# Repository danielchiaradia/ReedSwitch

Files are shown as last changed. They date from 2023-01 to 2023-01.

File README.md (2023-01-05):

# ReedSwitch
Simple Door/Window contact with low quiescence current of around 5µA (according to my cheap multimeter ...). There is quite some power loss on the ESP development board caused by the regulator, serial converter and other components. However, it will only be powered for a short amount time, so it's not worth going the hard naked ESP way here.

# BOM
- ESP01
- Attiny85
- LiFePO4 Battery
- 2 x 3K3 Ohm resistor
- 410 µF capacitor
- Reed Switch with two terminals or alternatively a normally closed reed switch.
- 1xP-Channel MOSFET (e.g.NDP6020P)

# How it works
The attiny will be turned on by the reed switch and then turns the ESP via the MOSFET on. The ESP sends the current state of the reed switch to a REST service. After sending the data, the ESP signals to the attiny to turn of the power.

# Quiescence current
Around 5-10 µA with closed reed switch. Open switch will cause around 20-30 µA current (probably the closed terminal draws some current)

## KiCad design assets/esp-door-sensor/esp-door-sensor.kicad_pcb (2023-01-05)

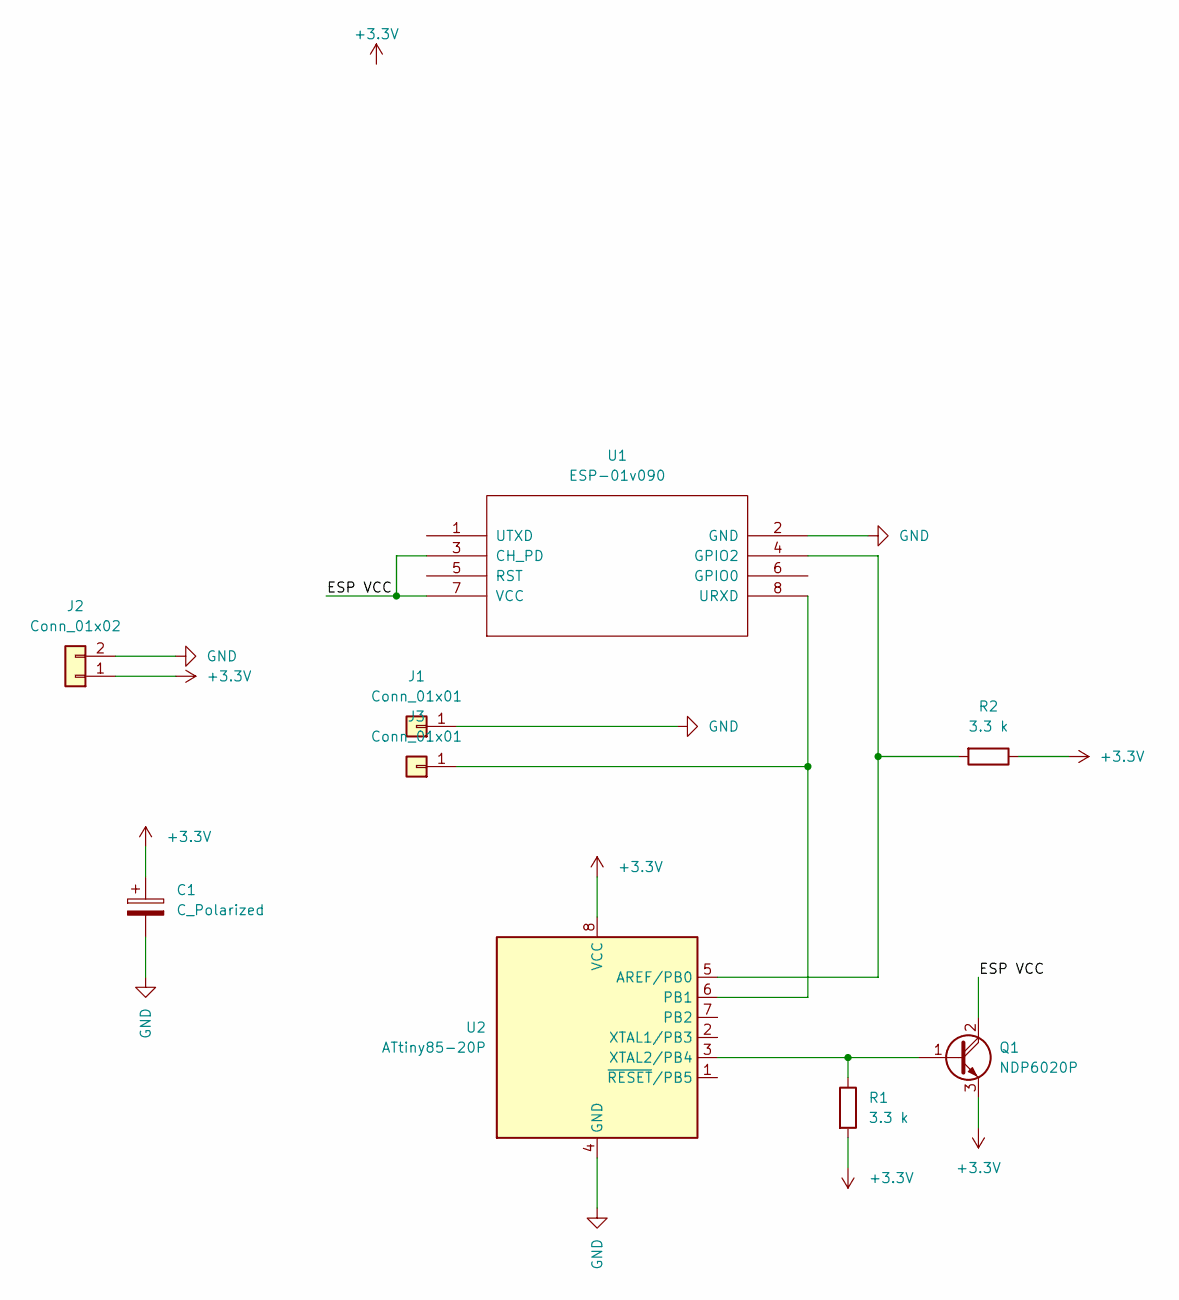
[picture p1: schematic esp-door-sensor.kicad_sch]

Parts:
C1: C_Polarized; CP_Radial_D6.3mm_P2.50mm
J1, J3: Conn_01x01; SolderWire-0.75sqmm_1x01_D1.25mm_OD2.3mm
J2: Conn_01x02; SolderWire-0.75sqmm_1x02_P7mm_D1.25mm_OD3.5mm
Q1: NDP6020P; TO-220-3_Vertical
R1, R2: 3.3 k; R_Axial_DIN0207_L6.3mm_D2.5mm_P7.62mm_Horizontal
U1: ESP-01v090; ESP-01
U2: ATtiny85-20P; DIP-8_W7.62mm

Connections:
+3.3V: C1.1, J2.1, Q1.3 (E), R1.2, R2.1, U2.8 (VCC)
/ESP VCC: Q1.2 (C), U1.3 (CH_PD), U1.7 (VCC)
GND: C1.2, J1.1, J2.2, U1.2 (GND), U2.4 (GND)
unnamed: Q1.1 (B), R1.1, U2.3 (XTAL2/PB4)
unnamed: R2.2, U1.4 (GPIO2), U2.5 (AREF/PB0)
unnamed: J3.1, U1.8 (URXD), U2.6 (PB1)

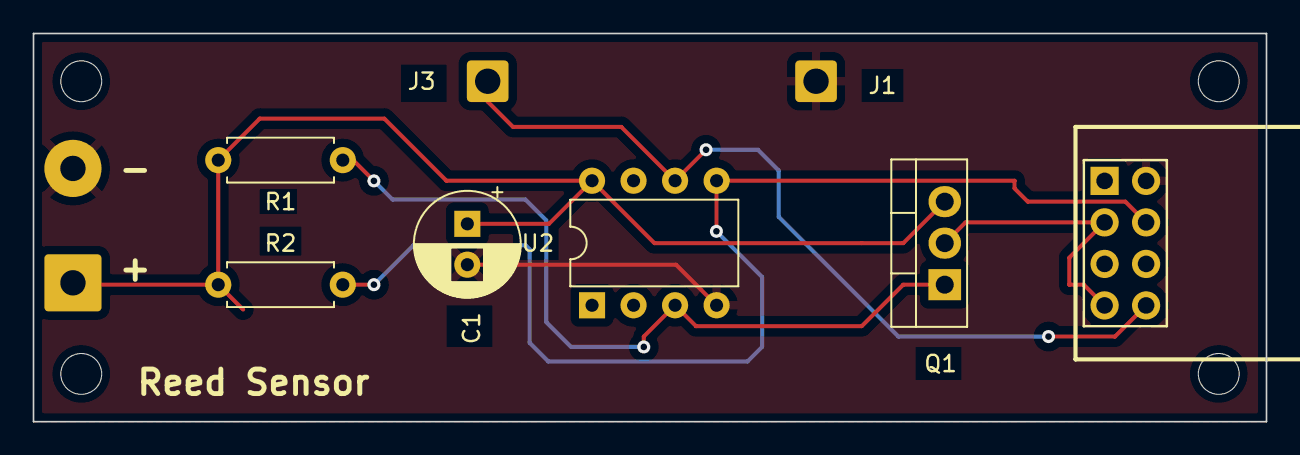
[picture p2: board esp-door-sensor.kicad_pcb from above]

Board: 2 copper layers, 75.4 x 23.7 mm, 9 parts (0 on the bottom side), 6 nets.

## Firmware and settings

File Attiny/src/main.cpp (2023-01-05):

#include <Arduino.h>
#include <avr/sleep.h>
#include <avr/interrupt.h>
#include <avr/wdt.h>

#define ESP_POWER_PIN PB4
#define SWITCH_INPUT_PIN PB1
#define ESP_POWER_IN_PIN PB0

void setup()
{
  pinMode(SWITCH_INPUT_PIN, INPUT);
  digitalWrite(SWITCH_INPUT_PIN, INPUT_PULLUP);
  pinMode(ESP_POWER_PIN, OUTPUT);
  digitalWrite(ESP_POWER_PIN, HIGH);

  pinMode(ESP_POWER_IN_PIN, INPUT_PULLUP);
}

void resetWatchDog ()
{
  MCUSR = 0;
  WDTCR = bit ( WDCE ) | bit ( WDE ) | bit ( WDIF ); // allow changes, disable reset, clear existing interrupt
  WDTCR = bit ( WDIE ) | bit ( WDP2 )| bit ( WDP1 ); // set WDIE ( Interrupt only, no Reset ) and 1 second TimeOut
                                                     
  wdt_reset();                            // reset WDog to parameters
  
} // end of resetWatchDog ()


void sleep()
{

  GIMSK |= _BV(PCIE);                  // Enable Pin Change Interrupts
  PCMSK |= _BV(PCINT1);                // Use PB1 as interrupt pin
  ADCSRA &= ~_BV(ADEN);                // ADC off
  set_sleep_mode(SLEEP_MODE_PWR_DOWN);

  sleep_enable();
  sei();          // Enable interrupts
  sleep_cpu();    // sleep

  cli();                 // Disable interrupts
  PCMSK &= ~_BV(PCINT1); // Turn off PB1 as interrupt pin
  sleep_disable();       // Clear SE bit
  ADCSRA |= _BV(ADEN);   // ADC on

  sei(); // Enable interrupts
} // sleep

ISR(PCINT0_vect)
{
  // This is called when the interrupt occurs, but I don't need to do anything in it
}

void loop()
{
  sleep();
  digitalWrite(ESP_POWER_PIN, LOW);
  delay(500);
  int maxDelay = 15000;
  while (digitalRead(ESP_POWER_IN_PIN) == LOW && maxDelay > 0) {
    delay(1);
    maxDelay--;
  }
  digitalWrite(ESP_POWER_PIN, HIGH);
}

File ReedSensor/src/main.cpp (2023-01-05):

#include <Arduino.h>
#include <ESP8266WiFi.h>
#include <ESP8266HTTPClient.h>
#include "Secrets.h"

#define VCC_SWITCH 2
#define REED_INPUT 3

ADC_MODE(ADC_VCC);

uint32_t getWifiChannel(String ssid)
{
  int networksFound = WiFi.scanNetworks();
  int i;
  for (i = 0; i < networksFound; i++)
  {
    if (ssid == WiFi.SSID(i))
    {
      return WiFi.channel(i);
    }
  }
  return -1;
}

void setupWiFi()
{
  // Serial.println("WiFi Setup...");
  IPAddress local_IP(192, 168, 178, 49);
  IPAddress gateway(192, 168, 178, 1);
  IPAddress subnet(255, 255, 255, 0);
  WiFi.config(local_IP, gateway, subnet);
  WiFi.mode(WIFI_STA);
  WiFi.hostname(HOSTNAME);

  int channel = getWifiChannel(WIFI_SSID);
  WiFi.begin(WIFI_SSID, PASSWORD, channel, bssid);
  WiFi.persistent(true);
  WiFi.setAutoConnect(true);
  WiFi.setAutoReconnect(true);
}

void sendState(int start)  
{
  HTTPClient http;
  String state = digitalRead(REED_INPUT) ? "closed" : "open";
  http.begin(callback + state + "/" + ESP.getVcc() + "/" + (millis() - start));
  http.GET();
  // Serial.println("Sent");
}

void setup()
{
  pinMode(VCC_SWITCH, OUTPUT);
  digitalWrite(VCC_SWITCH, LOW);
  pinMode(REED_INPUT, INPUT_PULLUP);
  // delay(5000);
  long st = millis();
  // Serial.begin(74880);
  
  if (WiFi.SSID() != WIFI_SSID)
  {
    setupWiFi();
  }

  if (WiFi.waitForConnectResult(6000) == WL_CONNECTED)
  {
    sendState(st);
  }
  else 
  {
    // channel changed
    // Serial.println("Could not connect to WiFi ...");
    setupWiFi();
    if (WiFi.waitForConnectResult(6000) == WL_CONNECTED)
    {
      sendState(st);
    }
  }

  digitalWrite(VCC_SWITCH, HIGH);
}

void loop()
{
  // Set GPIO 3 to high should cut VCC anyways
  ESP.deepSleep(10000000);
}

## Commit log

2021-12-04 Normaly closed switch
2021-12-11 Images and Fusion360 file
    [DoorSwitch.f3d, Sketch.fzz, case.stl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]
2023-01-05 PCB finalized
    [DoorSwitch.f3d, Sketch.fzz, case.stl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]
